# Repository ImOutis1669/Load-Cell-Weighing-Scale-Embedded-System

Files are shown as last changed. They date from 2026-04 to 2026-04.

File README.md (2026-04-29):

# Embedded System Weighing Scale (Load Cell-Based)

## Overview
This project implements a **digital weighing scale system** using a load cell sensor and embedded processing.  

It demonstrates the full signal chain from **analogue sensing → signal conditioning → digital processing**, combining hardware and software to produce accurate weight measurements.

---

## Features
- Load cell-based weight sensing  
- Signal conditioning for low-level analogue signals  
- Microcontroller-based data acquisition and processing  
- Real-time weight measurement output  
- System calibration and validation  
- Integrated hardware and software design  

---

## System Architecture

The system is composed of multiple stages:

### Sensing Stage
- Load cell converts applied force into a small electrical signal  
- Produces low-level analogue voltage proportional to weight  

### Signal Conditioning
- Amplification of the load cell output  
- Improves signal strength for accurate measurement  
- Reduces noise and stabilises readings  

### Data Acquisition & Processing
- Microcontroller reads conditioned signal  
- Converts analogue signal to digital values  
- Applies scaling and calibration to output weight  

### Output Stage
- Displays or transmits processed weight data  
- Provides real-time feedback to the user  

---

## System Operation

1. Load is applied to the weighing platform  
2. Load cell generates a corresponding analogue signal  
3. Signal is amplified and conditioned  
4. Microcontroller processes and converts the signal  
5. Final weight value is output in real time  

---

## Testing & Validation
- Calibrated system using known weights  
- Compared measured values with expected results  
- Analysed accuracy and repeatability  
- Refined system performance through iterative testing  

---

## Hardware Components
- Load cell  
- Signal conditioning circuitry (amplifier)  
- Microcontroller (Arduino / similar)  
- Weighing platform and structural components  
- Power supply  

---

## Project Structure

/src → Embedded code
/schematics → Circuit design
/docs → Reports and analysis
/images → System photos

---

##  Team Contribution
This project was developed as part of a **collaborative team effort**, with shared responsibilities across system design, implementation, and testing.  

My contributions focused on:
- Signal acquisition and embedded data processing  
- System integration across sensing and processing stages  
- Calibration, testing, and validation of measurement accuracy  

---

## Key Learnings
- Working with **analogue sensor signals and amplification**  
- Interfacing sensors with microcontrollers  
- Performing **system calibration and validation**  
- Designing full **end-to-end embedded systems**  
- Debugging hardware and improving measurement accuracy  

---

## Future Improvements
- Improve signal filtering and noise reduction  
- Increase measurement resolution  
- Add digital display interface (LCD/OLED)  
- Implement data logging or wireless transmission  
- Enhance calibration algorithms  

---

## Author
**Jeremy Antwi**  
Electrical & Electronic Engineering Student  
Interested in Embedded Systems, FPGA, and Hardware Design

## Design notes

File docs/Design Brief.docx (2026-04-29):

Design Brief – Weighing Scale

The product is a weighing scale designed for people who want to keep track of their bodyweight and monitor their health. It must be simple to use while still being efficient in order to maximise the target market.

It uses a TAL220 Parallel Beam Load Cell [1] to measure the weight, and a HX711 Load Cell amplifier [2] – since Load Cells make small signals that cannot easily be detected by the Arduino, and the HX711 converts this analogue signal to a digital one. The weight on the scale will be displayed to the user using an LCD. The Arduino will be powered by a 9-volt battery.

The product shall:

- Read and display the weight placed on the scale.
- Have an indicator to show low battery.
- Have an indicator to show overload weight.

The product should:

- Have an LED indicator to indicate power to the circuit.
- Have a BMI calculator (user somehow enters height).
- Have Permanent Storage (Cloud Storage?)

Existing Products:

The RENPHO Digital Bathroom Scales are designed to weigh loads of up to 180kg for £12.29. It has no additional features such as BMI calculating or an LED indicator to show that it is on.

On the other end of the spectrum, the INSMART Bluetooth Scales (https://www.amazon.co.uk/Bluetooth-INSMART-Bathroom-Weighing-Composition/dp/B07Q9PS28M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) are much more complex. For £23.59, it has many additional features such as bone and muscle mass calculators as well as BMI calculator. This can all be viewed in an app that the user can download. The problem is that this increased complexity sacrifices ease of use and therefore inclusivity – as many people will not know how to connect the scales to the app. Additionally, many of these features will not be used by most people.

The weighing scale we are designing must be somewhere between these two complexities to make it intuitive and effective.

References

[1] SEN-13329 | Sparkfun TAL220 Series Parallel Beam Load Cell, 3 → 200kg Range, Compression Measure, 1000Ω | RS (https://uk.rs-online.com/web/p/strain-gauges/2836585?gb=s)

[2] HX711 24-Bit ADC Pinout, Datasheet, Interfacing Examples, Applications (https://microcontrollerslab.com/hx711-adc-weigh-scales/)

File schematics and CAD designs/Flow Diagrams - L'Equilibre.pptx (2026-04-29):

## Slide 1

Main

setup()

1. The setup() method is used to initialise variables, set baud rate and create the Scale objects used for measuring.
2. If the system has power, the Boolean variable tareFlag is checked to see if the TareSet interrupt has been called. If so, tareFlag = True and tareFunc() is called.

3) If false, the battery level is checked.
4) Then, totalWeight is calculated from both Scales and both Channels.
5) totalWeight is then checked to see if the weight exceeds 190lbs (the maximum for the load cells). If true, overload_warning() is called.
6) Otherwise, the totalWeight is displayed on the LCD.

End

No

Does system have power?

Is tareFlag = True?

checkBattery()

Yes

Yes

tareFunc()

Calculate totalWeight from all four Load Cells

Is totalWeight > 190kg?

Display totalWeight on LCD

Yes

No

overload_warning()

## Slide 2

setup()

Initialise LCD screen

Initialise buttons and attach interrupts.

start_screen()

1. LCD screen and baud rate for serial communication are initialised.
2. Button connections are set, and relevant interrupts are attached to each (ISR_TareSet to Tare Button, ISR_Unit to Unit Button). Pullup resistors are enabled to ensure the buttons either give a 0 or a 1.
3. Two methods, start_screen() and initialise_HX711_modules() are called.
4. Both scales on both channels are calibrated.
5. The main loop() is then reached.

Initialise_HX711_modules()

Calibrate both scales in both channels

loop()

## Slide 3

start_screen()

Display introductory message

1500ms delay

Return

1. Once called, introductory message shown to the user – letting them know that the scale is on.
2. 1.5 second delay to leave the message on the screen.
3. Returns to setup() method.

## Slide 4

initialize_HX711_modules()

Initialise HX711 connections

1. Once called, connections are initialised for each HX711.
2. A while loop is used to check if both HX711 modules are ready. This is done by using the “is_ready()” method that is built into the HX711 library. It returns a Boolean value (True/False) that is used to control the iteration.
3. If either of the modules are not ready, a suitable message such as “Please connect HX711” will be displayed on the LCD screen.
4. Otherwise, the user is notified that the HX711 modules are connected via a suitable message on the LCD screen – “HX711 ready!”
5. Returns to the setup() method.

Are both modules ready?

Display suitable message

Return

Display suitable message

No

Yes

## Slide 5

channel_change(int gain)

Set gain for Scale 1

Set gain for Scale 2

Return

1. One integer argument is expected by the method (gain).
2. Gain is set for the HX711 modules using the “set_gain” method which is built into the HX711 library.
3. The gain relates to which channel is being read from. A gain of 64 is Channel A, a gain of 32 is Channel B. These must be switched between to read from both load cells attached to a module – hence why this method is mandatory.
4. Returns to main code.

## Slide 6

measure_scaleX()

Get measurement from scale X and store it in a float variable

*X = 1, 2

1. There are two versions of the function – one for each of the two HX711 modules.
2. The loadcell is measured, and the result is stored in a floating-point variable.
3. If the variable is less than 0, it is simply set to 0 to prevent false readings.
4. If the variable is greater than 0, the variable is returned to the program for more calculations.

Is variable > 0?

No

Variable = 0

Yes

Return variable

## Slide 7

overload_warning()

Display warning message

1000ms delay

Return

1. This method is called if the total reading from both loadcells in both channels (in pounds) exceeds 190lbs.
2. A warning message is then displayed until the load on the scale drops below 190lbs.

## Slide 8

tareFunc()

Tare both HX711

Set initialWeight to 0

Display suitable message

Return

1. HX711 modules are tarred on both channels.
2. initialWeight is reset.
3. A suitable message is outputted to the user.
4. Returns to the main program.

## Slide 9

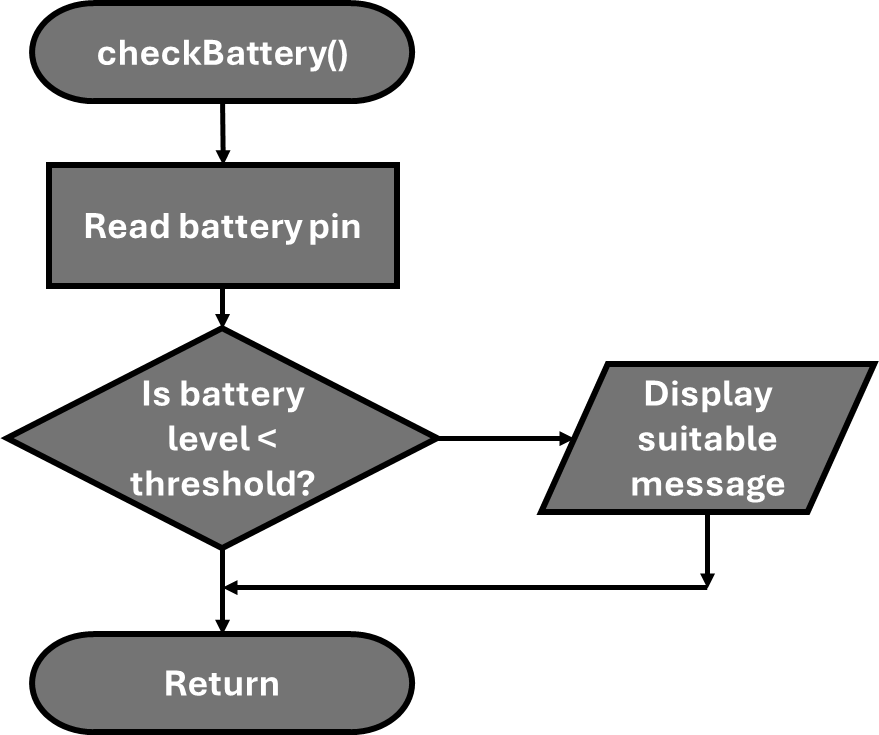
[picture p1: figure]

1. When called, this method reads the voltage on one of the analog pins – scaled down with a voltage divider.
2. If the level is lower than the threshold, a suitable message is displayed.
3. Otherwise, return to main program.

Yes

No

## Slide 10

ISR_TareSet()

tareFlag = True

Return

1. The interrupt turns the volatile Boolean variable tareFlag to true.
2. This value is returned to the main program, where a selection statement is used to trigger TareFunc(). tareFlag resets to false in the selection statement to prevent it triggering again.
3. The code stored in TareFunc() could be stored in this ISR, however ISRs should be kept short. This is because interrupts can block other interrupts – meaning other button presses could be missed.

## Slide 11

ISR_Unit()

Increment unitMode

Return

1. When called, unitMode is incremented. unitMode is declared volatile so its value is always checked as its value can change at any time.
2. The variable counts from 0-3 (inclusive) and each value relates to a measurement (0 = kg, 1 = g, 2 = lbs, 3 = st).
3. The selection statement used in main converts the integer into a comprehensible string.

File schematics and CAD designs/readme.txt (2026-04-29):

/*
  ___     .__/\___________            .__.__  ._____.                    ___     
 / _ \_/\ |  )/\_   _____/ ________ __|__|  | |__\_ |_________   ____   / _ \_/\ 
 \/ \___/ |  |  |    __)_ / ____/  |  \  |  | |  || __ \_  __ \_/ __ \  \/ \___/ 
          |  |__|        < <_|  |  |  /  |  |_|  || \_\ \  | \/\  ___/           
          |____/_______  /\__   |____/|__|____/__||___  /__|    \___  >          
                       \/    |__|                     \/            \/           		*/

This folder contains everything related to the Mechanical Design including:
- SolidWorks Parts and Assembly Files
- Handmade Drawings of Design Concept/Prototype
- Screen Captures of all the SolidWorks Files
------------------------------------------------------------------------------------------------------
By Jeremy Antwi - Hardware/Mechanical Lead.

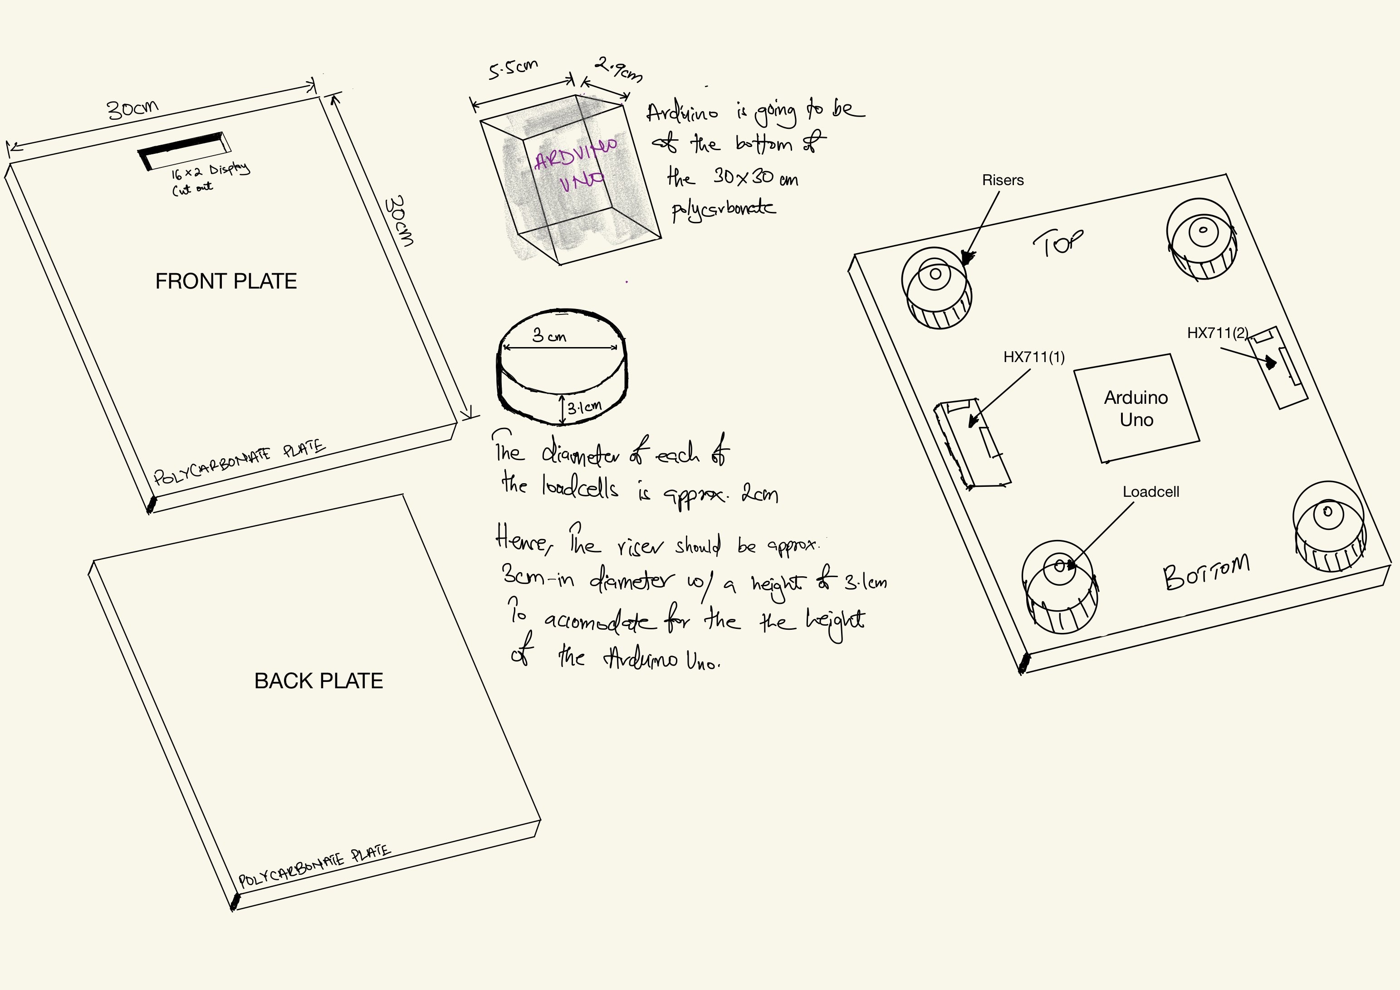
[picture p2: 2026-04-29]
schematics and CAD designs/Design Concept.jpg

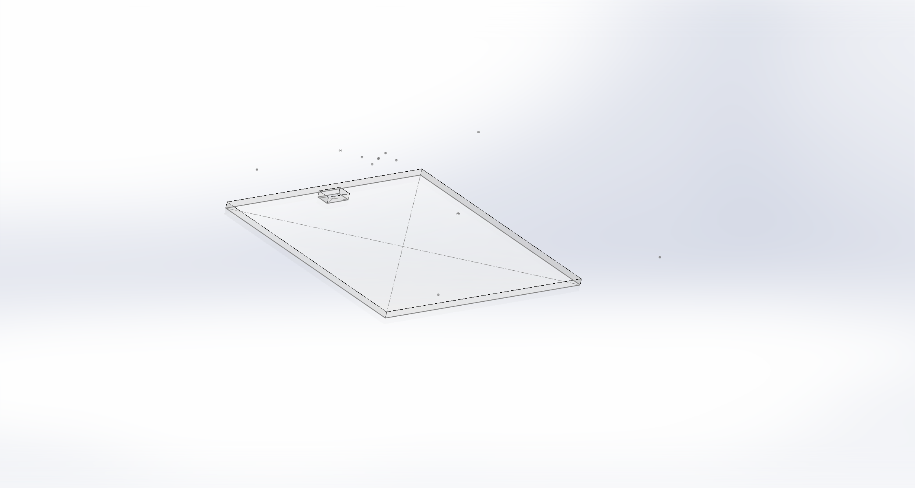
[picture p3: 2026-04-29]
images/Screen Captures of SolidWorks CAD/Weighing Scale - SideProfile.PNG

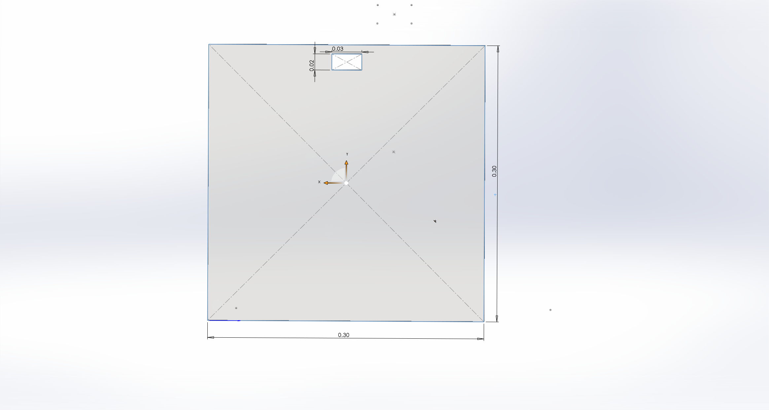
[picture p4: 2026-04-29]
images/Screen Captures of SolidWorks CAD/Weighing Scale - FrontProfile.PNG

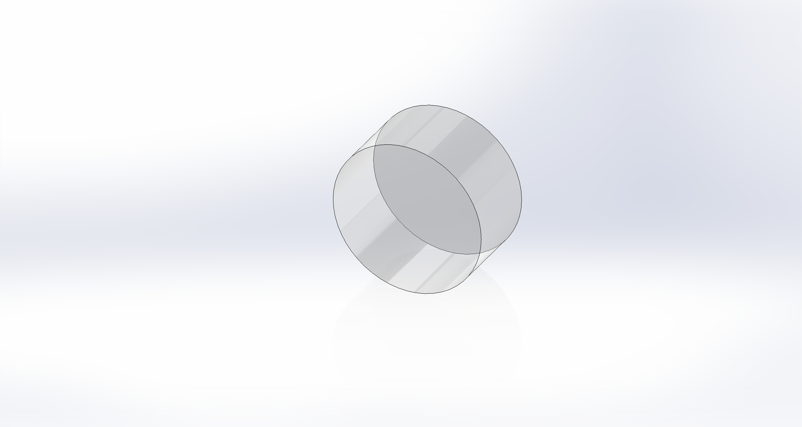
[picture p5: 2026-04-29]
images/Screen Captures of SolidWorks CAD/Risers image.PNG

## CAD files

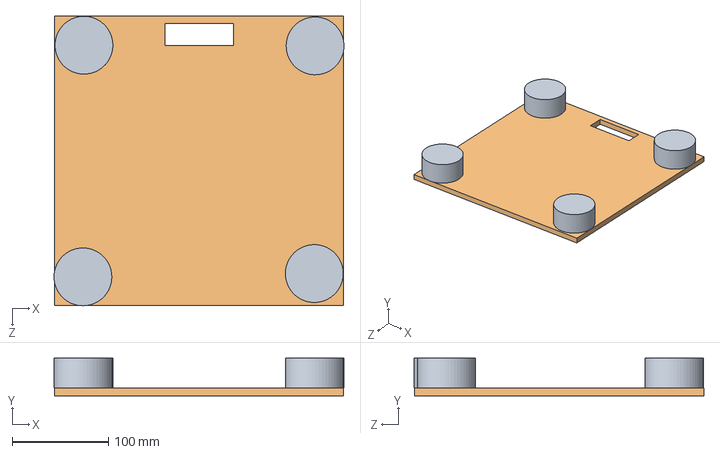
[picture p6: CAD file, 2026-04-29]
schematics and CAD designs/Solidwork CAD Files/Completed Weighing scale.SLDASM
300.8 x 39.0 x 300.4 mm
Weighing Scale - Updated LCD Cutout
Risers x 4

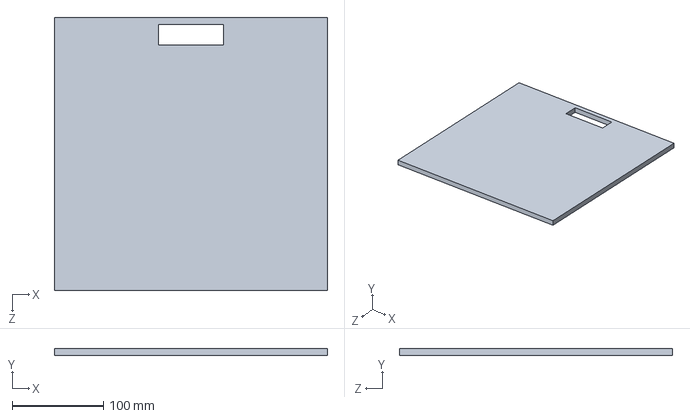
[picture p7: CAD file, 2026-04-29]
schematics and CAD designs/Solidwork CAD Files/Weighing Scale - Updated LCD Cutout.SLDPRT
300.0 x 8.00 x 300.0 mm

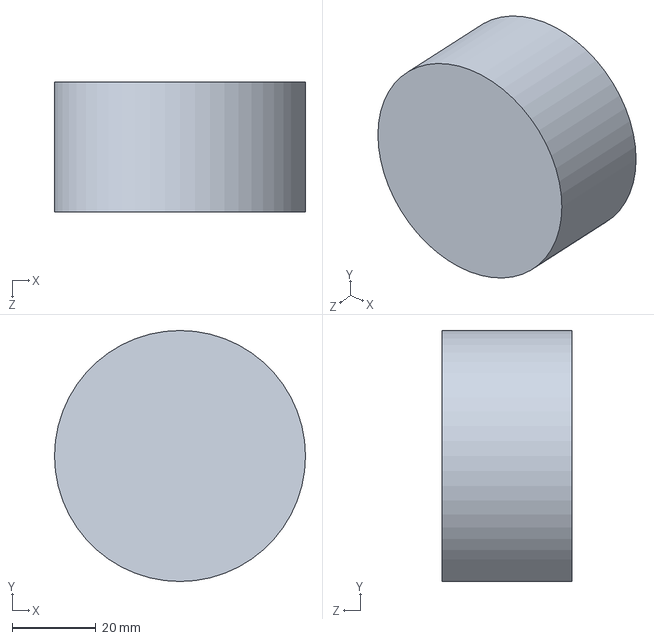
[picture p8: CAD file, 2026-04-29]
schematics and CAD designs/Solidwork CAD Files/Risers.SLDPRT
60.0 x 60.0 x 31.0 mm

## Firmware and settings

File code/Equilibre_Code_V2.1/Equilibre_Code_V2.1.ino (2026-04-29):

#include <HX711.h>
#include <Arduino.h>
#include <rgb_lcd.h>

/*
    Project Name: L'Equilibre
    Author: John Pritchard & Jeremy Antwi
    Date: 24/03/2025
    Version: 2.1
    
    Description: 
      This code allows the user to weigh themselves and other items. This is done by taking the data from the load cells
      and converting it into the user's desired unit measurement (kilograms, grams, pounds, stone).
      The user has two buttons - one that can Tare the scale (reset reading to 0) and one that can 
      change the measuremnt units. 
      
      2.1 (27/03/2025): Rewrote the main logic. Takes the highest reading and displays it now in an attempt to prevent fluctuations.
      2.0 (27/03/2025): Hard coded the weight of the plate out. Not ideal, however it is functional.
      1.9 (24/03/2025): Added Check Battery Level method that displays a warning when value drops below a certain threshold. Added red backgrounds for the warnings. General organisation improvements of the code.
      1.8 (22/03/2025): Added Channel Change - allowing all 4 load cells to be read by alternating between Channel A to Channel B. Changed LCD Screen, so different library used.
      1.7 (21/03/2025): Added debounce on button interrupts to prevent false triggering. Fixed the issue where units button would sometimes trigger both Unit and Tare ISR.
      1.6 (29/02/2025):	Added overload warning when the measured value exceeds 190lbs.
      1.5 (29/02/2025):	Improved formatting of scale. Fixed bug where the "Tare Applied" message wouldn't show if used in an ISR. Used a flag variable instead. 
      1.4 (28/02/2025): Got interrupts working. Problem caused by lack of libraries. Need to work on formatting of LCD.
      1.3 (20/02/2025): Implemented grams measurement to allow users to use the scales in more scenarios - such as weighing food (as per the brief).
      1.2 (15/02/2025): Implemented start screen.
      1.1 (14/02/2025): Added and refined main functionality of scale and buttons. The buttons could be further enhanced using interrupts.
      
    Hardware:
      - ATmega328 Arduino Uno Board
      - 2 Push Buttons (Pin 2 and 3)
      - 2 HX711 - scale_1 (Pin 6 and Pin 7) and scale_2 (Pin 4 and Pin 5)
      - 4 Load Cells (2 for each HX711)
      
*/

rgb_lcd lcd;

//Define HX711 connections
const int LOADCELL_DOUT_PIN_1 = 5;
const int LOADCELL_SCK_PIN_1 = 4;
const int LOADCELL_DOUT_PIN_2 = 7;  
const int LOADCELL_SCK_PIN_2 = 6;   

//Button Pins 
const int TARE_BUTTON = 2;  //TARE Button
const int UNIT_BUTTON = 3;  //Unit Change Button

//Battery pin
const int VIN_PIN = A0;

//Create HX711 instances
HX711 scale_1;
HX711 scale_2;

//Variables to store initial weight
float initialWeight1 = 0;
float initialWeight2 = 0;

volatile int unitMode = 0;  //0 = kg, 1 = grams, 2 = lb, 3 = stone

volatile bool tareFlag = false;  //Flag to trigger tare function
bool batteryFlag = true;

//Calibration factors for each load cell - could be more accurate
const int calibrationFactor1A = 436.0181964;  
const int calibrationFactor2A = 340.3532245;  
const int calibrationFactor1B = 137.4632058;  
const int calibrationFactor2B = 296.5721167;  


// Conversion Constants
const float KG_TO_GRAMS = 1000;
const float KG_TO_LB = 2.20462;
const float KG_TO_STONE = 0.157473;

String unitStr = "";       //Stores the current unit
int decPlaces = 2;         //Decimal places for display (can be changed based on situation)

volatile unsigned long lastInterruptTime = 0;  
const unsigned long debounceDelay = 200; 

//Gain values for channels.
int channel_A = 64;
int channel_B = 32;

float division = 1;
float highest = 0;      //Stores highest value recorded

//Colours
byte red[3] = {255, 0, 0};
byte white[3] = {255, 255, 255};

float threshold = 20.0;     //If battery percentage goes below this number, a warning is displayed (Can be changed)

void setup() {
  //Initialise LCD screen
  Serial.begin(57600);
  lcd.begin(16, 2);

  //Initialise buttons and attach interrupts
  pinMode(TARE_BUTTON, INPUT_PULLUP);
  pinMode(UNIT_BUTTON, INPUT_PULLUP);
  attachInterrupt(digitalPinToInterrupt(TARE_BUTTON), ISR_TareSet, FALLING);
  attachInterrupt(digitalPinToInterrupt(UNIT_BUTTON), ISR_Unit, FALLING);

  start_screen();
  initialize_HX711_Modules();

  channel_change(channel_A);                  //Calibrate and tare scales in Channel A
  scale_1.set_scale(calibrationFactor1A);
  scale_2.set_scale(calibrationFactor2B);
  scale_1.tare();
  scale_2.tare();

  channel_change(channel_B);                  //Calibrate and tare scales in Channel B
  scale_1.set_scale(calibrationFactor1B);
  scale_2.set_scale(calibrationFactor2B);
  scale_1.tare();
  scale_2.tare();

  initialWeight1 = 0;  
  initialWeight2 = 0;

  lcd.clear();
  delay(1000);
}


void loop() { 
  if (tareFlag) { 
    tareFunc();
    tareFlag = false;  //Reset flag
  }

  check_batteryLevel();   

  lcd.clear();
  lcd.print("Step On");
  delay(7000);
  lcd.clear();
  lcd.print("Calculating");

  for (int x = 0; x < 10; x++){               //Repeats to get the highest value
    channel_change(channel_A);                //Get Channel A readings
    float channelA1 = measure_scale1();
    float channelA2 = measure_scale2();

    channel_change(channel_B);                //Get Channel B readings. Output scaled since Channel B has less gain
    float channelB1 = measure_scale1() * 2;   
    float channelB2 = measure_scale2() * 2;   

    float totalWeight = (channelA1 + channelA2 + channelB1 + channelB2);       //Total all readings from both HX711 and both Channels

    if (totalWeight > highest){
    highest = totalWeight;
    }
  }

  delay(3000);
  float displayWeight = highest -15.2;                //Takes weight of plate off
  if (unitMode == 0) {
      unitStr = "kg";         
      division = 1;
  } else if (unitMode == 1) {
      displayWeight = (displayWeight * KG_TO_GRAMS);
      unitStr = "g";
      division = KG_TO_GRAMS;
  } else if (unitMode == 2) {
      displayWeight = (displayWeight * KG_TO_LB);
      unitStr = "lb";
      division = KG_TO_LB;
  } else if (unitMode == 3) {
      displayWeight = (displayWeight * KG_TO_STONE);
      unitStr = "st";
      division = KG_TO_STONE;
  }

  if ((displayWeight/division) > 190){			    //Converts back to kg for comparison (as a value in grams will appear much larger to the computer)
    overloadWarning();		  		                //When weight exceeds 190, warning is displayed
  } else {

    if (displayWeight < 0) displayWeight = 0;        //If displayWeight < 0, it becomes 0
    displayWeight = displayWeight / 2;
    
    lcd.clear();    
    lcd.setRGB(white[0], white[1], white[2]);
    lcd.setCursor(0, 0);
    lcd.print("Total: ");
    lcd.setCursor(0, 1);
    lcd.print(displayWeight, decPlaces);		    //Prints display weight to 2dp (Can be changed to ndp at the top)
    lcd.print(" " + unitStr + " ");
    delay(5000);
    lcd.clear();

    lcd.print("Step Off");
    delay(5000);
    highest = 0;
  } 
}


// Functions ----------------------------------

void start_screen() {
  delay(500);
  lcd.setCursor(2, 0);
  lcd.print("L'Equilibre");
  delay(1000);
  lcd.setCursor(7, 1);
  lcd.print(":)");
  delay(1500);
}

void initialize_HX711_Modules(){
  //Initialize HX711 A and B
  scale_1.begin(LOADCELL_DOUT_PIN_1, LOADCELL_SCK_PIN_1);
  scale_2.begin(LOADCELL_DOUT_PIN_2, LOADCELL_SCK_PIN_2);

  //Makes sure BOTH HX711 are connected.
  while (!(scale_1.is_ready() || scale_2.is_ready())) {
	  lcd.clear();
	  delay(500);
    lcd.print("~Connect HX711!~");
    delay(500);
  }
  //If both are connected, suitable message is given.
  lcd.clear();
  lcd.print("HX711 Ready!");
  delay(200);
}


void channel_change(int gain){   //Channel A = 64, Channel B = 32
  scale_1.set_gain(gain);
  scale_2.set_gain(gain);
}

float measure_scale1(){
  float returnValue = initialWeight1 + (scale_1.get_units(1) / 1000.0);
  if (returnValue < 0) returnValue = 0;               
  return returnValue;
}

float measure_scale2(){
  float returnValue = initialWeight2 + (scale_2.get_units(1) / 1000.0);
  if (returnValue < 0) returnValue = 0;                                     //Prevent negative values
  return returnValue;
}

void overloadWarning() {
  lcd.clear();    
  lcd.setRGB(red[0], red[1], red[2]);
  lcd.setCursor(0, 0);
  lcd.print("Overload Warning");
  lcd.setCursor(1, 1);
  lcd.print("Max: 190 lbs");
  delay(1000);

  //Reset Display
  lcd.clear();
  lcd.setRGB(white[0], white[1], white[2]);
}

void check_batteryLevel(){
  int VIN_reading = analogRead(VIN_PIN);    //Reads voltage put into A0 
  
  float scaledVoltage = (VIN_reading / 1023.0) * 5;     //1023 is mapped to reference voltage (5v)
  float actualBatteryVoltage = scaledVoltage * 2;       //*2 due to voltage divider
  float percentage = (actualBatteryVoltage/4.5) * 100;

  if ((percentage < threshold) && (batteryFlag == true)){
    lcd.setRGB(red[0], red[1], red[2]);
    lcd.clear();    
    lcd.setCursor(0, 0);
    lcd.print("Battery Low!");
    delay(5000);              //5 second delay to make sure the user is notified
    batteryFlag = false;      //Makes sure warning only happens once

    //Reset Display
    lcd.clear();
    lcd.setRGB(white[0], white[1], white[2]);
  }

  if (percentage >= 20){
    batteryFlag = true;       //Resets the warning if battery is charged/replaced
  }
}

void tareFunc() {
  //Tare both scales, reset initialWeight
  channel_change(channel_A);
  scale_1.tare();
  scale_2.tare();

  channel_change(channel_B);
  scale_1.tare();
  scale_2.tare();

  initialWeight1 = 0;
  initialWeight2 = 0;

  //Display this to the user
  lcd.clear();
  lcd.setCursor(2, 0);
  lcd.print("Tare Applied");
  delay(2000);
  lcd.clear();
}

// Interrupt Service Routines (ISRs) ----------

void ISR_TareSet() {
  unsigned long currentTime = millis();                         //Returns how long in ms the Arduino has been running
  if ((currentTime - lastInterruptTime) >= debounceDelay) {     //Debounce button to prevent two triggers

    tareFlag = true;                       //Set tare flag
    lastInterruptTime = currentTime;       //Update the last interrupt time
  }
}

void ISR_Unit() {
  unsigned long currentTime = millis();  
  if ((currentTime - lastInterruptTime) >= debounceDelay) {    //Debounce button to prevent two triggers

    unitMode = (unitMode + 1) % 4;        //Cycle through 0-3 (inclusive) - each number represents a unit
    lastInterruptTime = currentTime;      //Update the last interrupt time
  }
}


/*
  ___     .__/\___________            .__.__  ._____.                    ___     
 / _ \_/\ |  )/\_   _____/ ________ __|__|  | |__\_ |_________   ____   / _ \_/\ 
 \/ \___/ |  |  |    __)_ / ____/  |  \  |  | |  || __ \_  __ \_/ __ \  \/ \___/ 
          |  |__|        < <_|  |  |  /  |  |_|  || \_\ \  | \/\  ___/           
          |____/_______  /\__   |____/|__|____/__||___  /__|    \___  >          
                       \/    |__|                     \/            \/           		*/
